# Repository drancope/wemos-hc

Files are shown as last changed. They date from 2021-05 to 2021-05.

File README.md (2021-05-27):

# This is first basic info for a Wemos Home Control project.
The first atempt was built in summer 2020, controls two ceiling lamps, and uses a wemos wired to the main door switches and to a kicad home made PCB with a pair of opto-couplers (moc3121) and triacs (bt136). It's been working for a year with only two reset problemas, before I engage in this description of the project and a propper redesign.
Two more wemos are also used to emit wifi orders (post http method). These ones are placed in the bed sides for convenience.
The main server creates its own local wifi lan, and mobile phones can get an ip and access the wemos web server, displaying a page where the user can turn on/off the lights.
Code is based on ESP8266 examples

# Goals:
- learning and experimenting with mc and electronics
 -- programming servers, use of wifi libraries
 -- making PCBs with power devices

- use of wemos minicontrollers to switch lights at home,
  -- server to accept mobile orders
  -- reliable if home router fails
  -- initially, does not depend on iot standards, but considering learning about that.
  
- Expandable
 -- accepting internet orders
   --- a second wemos wired to main wemos, to provide connection to local network.
   --- future use of cloud computing, or aws iot messages.

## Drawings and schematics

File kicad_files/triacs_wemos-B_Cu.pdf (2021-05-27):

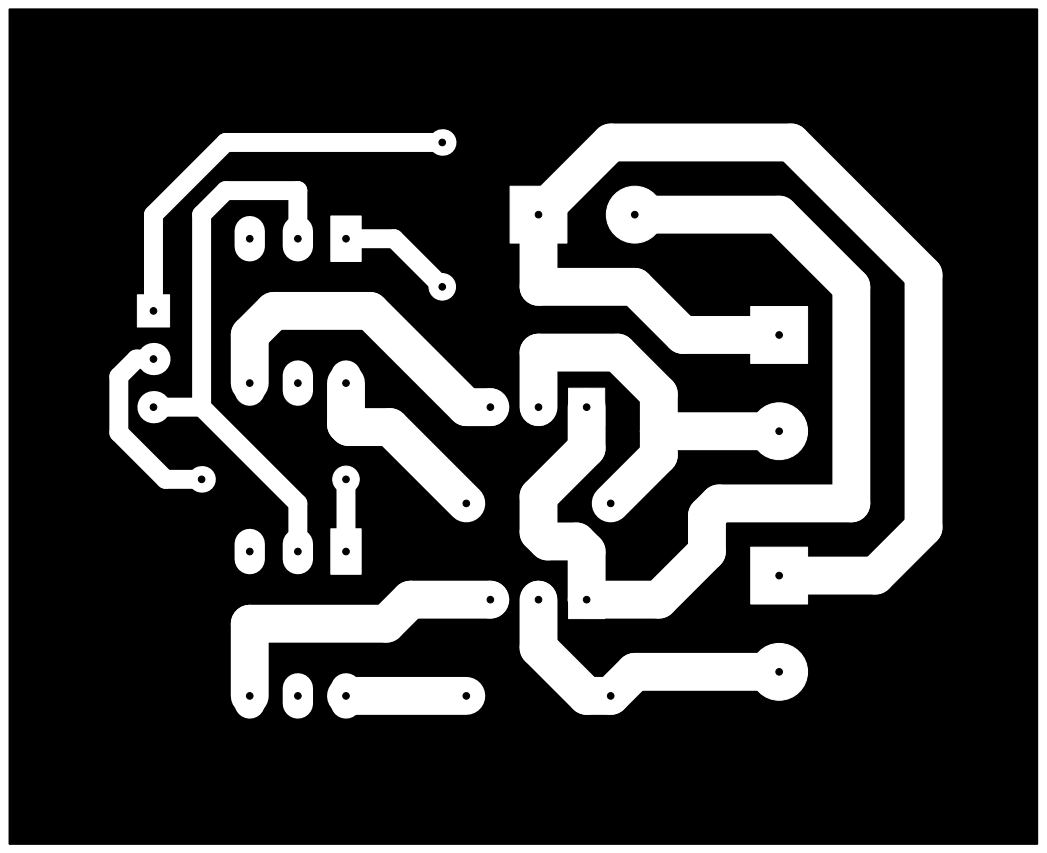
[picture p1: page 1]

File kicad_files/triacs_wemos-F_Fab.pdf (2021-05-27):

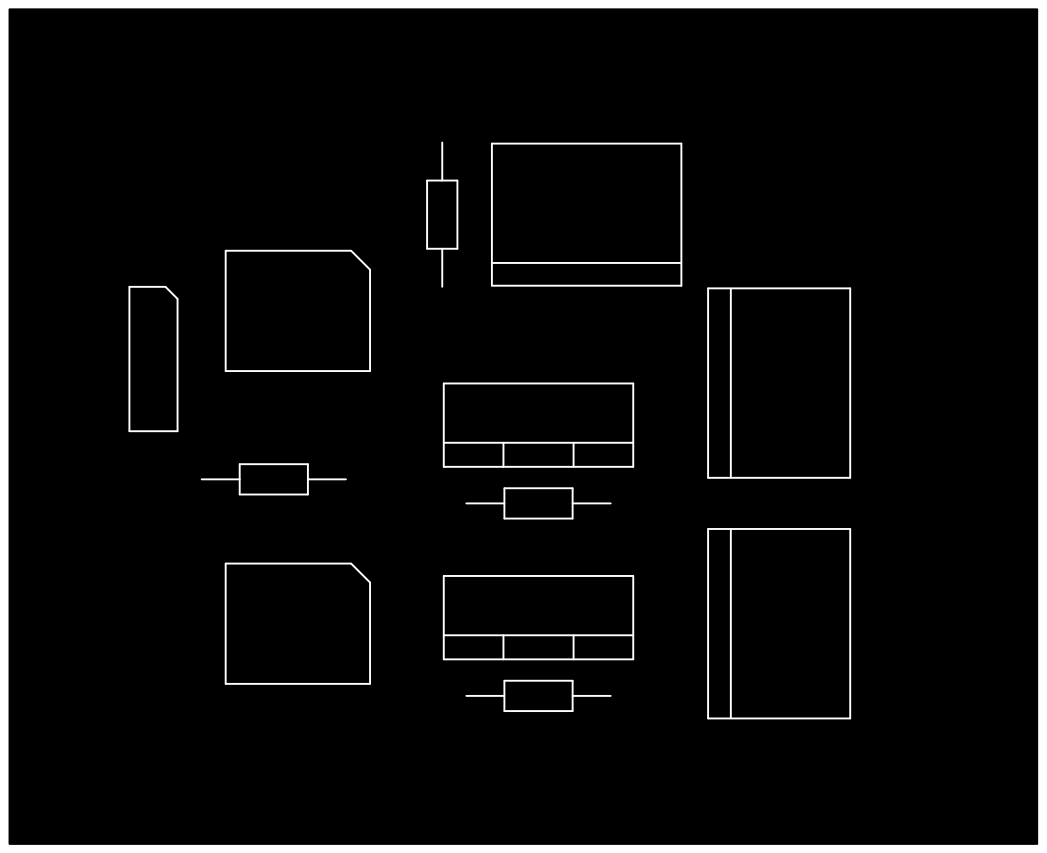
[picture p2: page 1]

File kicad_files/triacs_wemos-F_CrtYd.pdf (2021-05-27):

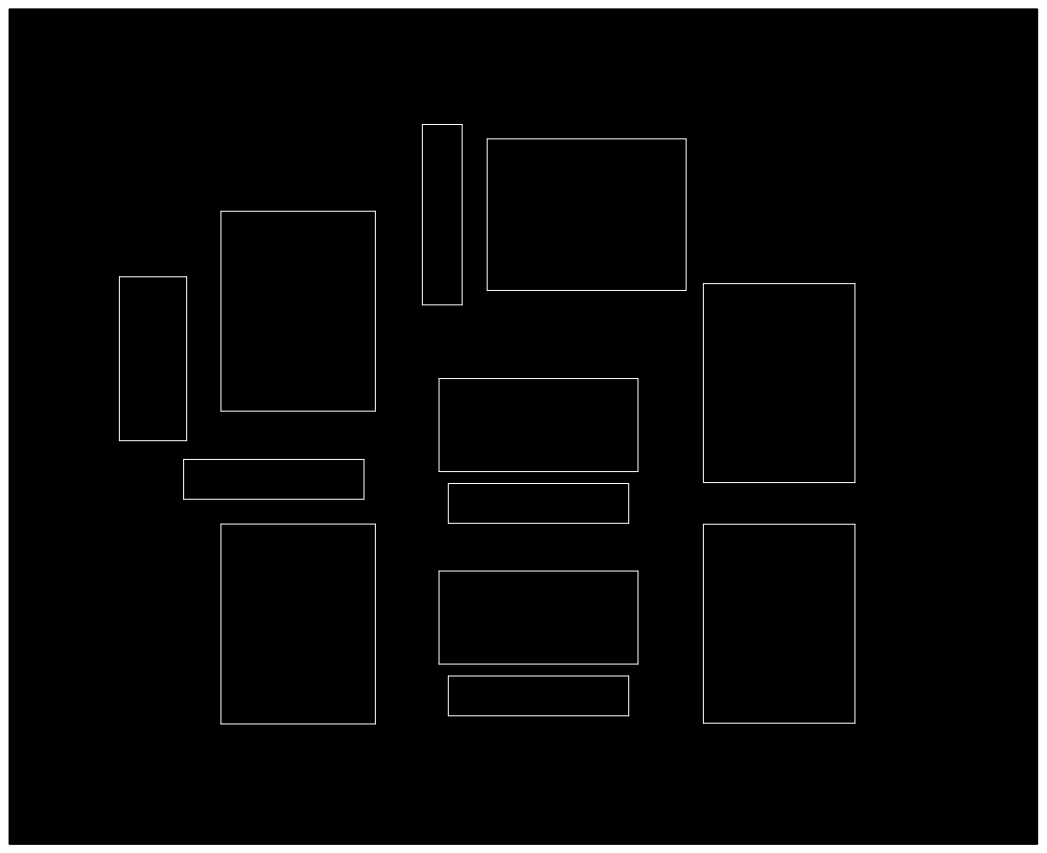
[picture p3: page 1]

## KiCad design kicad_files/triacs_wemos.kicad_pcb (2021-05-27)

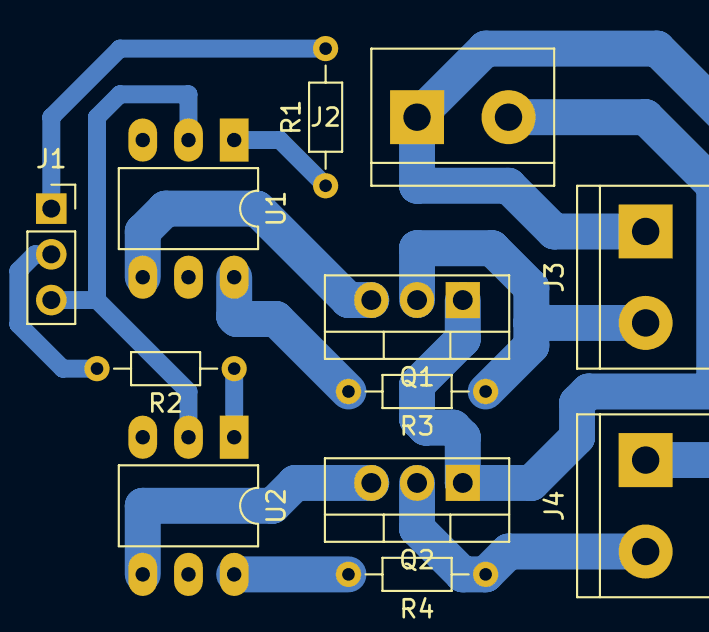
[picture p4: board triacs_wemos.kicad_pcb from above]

Board: 2 copper layers, 12 parts (0 on the bottom side), 13 nets.

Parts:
J1: Wemos; PinSocket_1x03_P2.54mm_Vertical
J2: Alim-altern; TerminalBlock_bornier-2_P5.08mm
J3: Luz 1; TerminalBlock_bornier-2_P5.08mm
J4: Luz 2; TerminalBlock_bornier-2_P5.08mm
Q1, Q2: BT136-600; TO-220-3_Vertical
R1, R2, R3, R4: R; R_Axial_DIN0204_L3.6mm_D1.6mm_P7.62mm_Horizontal
U1, U2: MOC3021M; DIP-6_W7.62mm_LongPads

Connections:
GND: J1.3, U1.2, U2.2
unnamed: J1.1, R1.2
unnamed: J1.2, R2.2
unnamed: J2.1, J3.1, J4.1
unnamed: J2.2, Q1.1, Q2.1
unnamed: J3.2, Q1.2, R3.1
unnamed: J4.2, Q2.2, R4.1
unnamed: Q1.3, U1.4
unnamed: Q2.3, U2.4
unnamed: R1.1, U1.1
unnamed: R2.1, U2.1
unnamed: R3.2, U1.6
unnamed: R4.2, U2.6

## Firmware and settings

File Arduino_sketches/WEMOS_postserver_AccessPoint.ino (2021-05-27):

#include <ESP8266WiFi.h>
#include <WiFiClient.h>
#include <ESP8266WebServer.h>
#include <ESP8266mDNS.h>
#include <string.h>

#ifndef STASSID
#define STASSID "your_wifi"
#define STAPSK  "your_wifi_passwd"
#endif
#ifndef APSSID
#define APSSID "this_wemos_wifi_access_point_name"
#define APPSK  "access_point_passwd"
#endif

#define SAL1 D3
#define SAL2 D2
#define ENT1 D5
#define ENT2 D6

const char *ssid     = APSSID;
const char *password = APPSK;
boolean estado1=0;
boolean estado2=0;

ESP8266WebServer server(80);

const int led = LED_BUILTIN;

const String postForms = "<html>\
  <head>\
    <title>ESP8266 Web Server POST handling</title>\
    <style>\
      body { background-color: #cccccc; font-size: xx-large; font-family: Arial, Helvetica, Sans-Serif; Color: #000088; }\
    </style>\
  </head>\
  <body>\
    <h1>POST plain text to /postplain/</h1><br>\
    <form method=\"post\" enctype=\"text/plain\" action=\"/postplain/\">\
      <div style=\"margin:10 80 40\">\
      <input type=\"submit\" style=\"font-size: 120px\" name=\"bot1\" value=\"1\"><br>\<br>\
      <input type=\"submit\" style=\"font-size: 120px\" name=\"bot2\" value=\"2\"><br>\
    </div>\
    </form>\
  </body>\
</html>";

const String redirige = "<html>\
    <head>\
        <meta http-equiv=\"refresh\" content=\"0; url=http://192.168.4.1/?\">\
<script type=\"text/javascript\">\
window.location.href = \"http://192.168.4.1\"\
</script>\
</head>\
</html>";


void handleRoot() {
  server.send(200, "text/html", postForms);
}

void handlePlain() {
  Serial.print(server.arg("plain"));
  
  if (server.method() != HTTP_POST) {
  //  server.send(405, "text/plain", "Method Not Allowed");
  } else {
   char dato = server.arg("plain")[5];
    if (dato=='1'){
      estado1 = !estado1;
      digitalWrite(SAL1, estado1);
    }
    else if (dato=='2') {
      estado2 = !estado2;
      digitalWrite(SAL2, estado2);
    }
   Serial.println(" recibido");
   Serial.print("Luz ");
   Serial.print(dato);
   switch(dato) {
    case '1':
     if (estado1==1) {Serial.println(" encendida");} else {Serial.println(" apagada");}
     break;
    case '2':
     if (estado2==1) {Serial.println(" encendida");} else {Serial.println(" apagada");}
     break;
    }
   }

    server.send(201, "text/html", redirige);
}
/*
void handleForm() {
  if (server.method() != HTTP_POST) {
  //  server.send(405, "text/plain", "Method Not Allowed");
  } else {
   char dato = server.arg("plain")[5];
   Serial.print(server.arg("plain"));
   Serial.println(" recibido");
    if (dato=='1'){
      estado1 = !estado1;
      digitalWrite(led, estado1);
    }
    else if (dato=='2') {
      estado2 = !estado2;
      digitalWrite(D3, estado2);
    }
    server.send(201, "text/html", redirige);
  }
}
*/
void handleNotFound() {
//  digitalWrite(led, 1);
  String message = "File Not Found\n\n";
  message += "URI: ";
  message += server.uri();
  message += "\nMethod: ";
  message += (server.method() == HTTP_GET) ? "GET" : "POST";
  message += "\nArguments: ";
  message += server.args();
  message += "\n";
  for (uint8_t i = 0; i < server.args(); i++) {
    message += " " + server.argName(i) + ": " + server.arg(i) + "\n";
  }
  server.send(404, "text/plain", message);
  Serial.println(message);
//  digitalWrite(led, 0);
}

void setup(void) {
  pinMode(SAL1, OUTPUT);
  pinMode(SAL2, OUTPUT);
  digitalWrite(SAL1, 0);
  digitalWrite(SAL2, 0);
  delay(400);
  Serial.begin(115200);
  Serial.println("");
  Serial.print("Configuring access point...");
  WiFi.softAP(ssid, password);
  IPAddress myIP = WiFi.softAPIP();
  Serial.print("AP IP address: ");
  Serial.println(myIP);
  server.on("/", handleRoot);
  server.on("/postplain/", handlePlain);
  server.onNotFound(handleNotFound);
  server.begin();
  Serial.println("HTTP server started");
  delay(1000);
  pinMode(SAL1, OUTPUT);
  pinMode(SAL2, OUTPUT);
  pinMode(ENT1, INPUT_PULLUP);
  pinMode(ENT2, INPUT_PULLUP);
  digitalWrite(SAL1, estado1);
  digitalWrite(SAL2, estado2);
}

void loop() {
  if (!digitalRead(ENT1)) {
    estado1 = !estado1;
    digitalWrite(SAL1, estado1);
    while(!digitalRead(ENT1)) {delay(20);}
  }
  if (!digitalRead(ENT2)) {
    estado2 = !estado2;
    digitalWrite(SAL2, estado2);
    while(!digitalRead(ENT2)) {delay(20);}
  }
  server.handleClient();
}

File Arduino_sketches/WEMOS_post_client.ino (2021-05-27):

/**
   PostHTTPClient.ino

    Created on: 21.11.2016

*/

#include <ESP8266WiFi.h>
#include <ESP8266HTTPClient.h>
#include <PolledTimeout.h>
#define USE_SERIAL Serial

/* this can be run with an emulated server on host:
        cd esp8266-core-root-dir
        cd tests/host
        make ../../libraries/ESP8266WebServer/examples/PostServer/PostServer
        bin/PostServer/PostServer
   then put your PC's IP address in SERVER_IP below, port 9080 (instead of default 80):
*/
//#define SERVER_IP "10.0.1.7:9080" // PC address with emulation on host
#define SERVER_IP "192.168.4.1"

#ifndef STASSID
#define STASSID "Wemos_access_point_name"
#define STAPSK  "access_point_password"
#endif
IPAddress ip(192, 168, 4, 2);
IPAddress gateway(192, 168, 4, 1);
IPAddress subnet(255, 255, 255, 0);
IPAddress dns1(192, 168, 4, 1);
//esp8266::polledTimeout::periodicFastUs halfPeriod(100000);

void setup() {
  pinMode(D5, INPUT_PULLUP);
  pinMode(D1, INPUT_PULLUP);

  USE_SERIAL.begin(115200);
  USE_SERIAL.println();

  WiFi.mode(WIFI_STA);
//  WiFi.config(ip, gateway, subnet, dns1);
  WiFi.begin(STASSID, STAPSK);

  while (WiFi.status() != WL_CONNECTED) {
    delay(500);
    USE_SERIAL.print(".");
  }
  USE_SERIAL.println("");
  USE_SERIAL.print("Connected! IP address: ");
  USE_SERIAL.println(WiFi.localIP());
 
}

void loop() {
  // wait for WiFi connection
  while (digitalRead(D5)) {
    yield();
  }
    if ((WiFi.status() == WL_CONNECTED)) {

    WiFiClient client;
    HTTPClient http;

    USE_SERIAL.print("[HTTP] begin...\n");
    // configure traged server and url
    http.begin(client, "http://"SERVER_IP"/postplain/"); //HTTP
    http.addHeader("Content-Type", "application/json");

    USE_SERIAL.print("[HTTP] POST...\n");
    // start connection and send HTTP header and body
    int httpCode = http.POST("bot1=1");
    USE_SERIAL.printf("[HTTP] POST... code: %d\n", httpCode);
        
    // httpCode will be negative on error
    if (httpCode > 0) {
      // HTTP header has been send and Server response header has been handled

      // file found at server
      if (httpCode == HTTP_CODE_OK) {
        const String& payload = http.getString();
        USE_SERIAL.println("received payload:\n<<");
        USE_SERIAL.println(payload);
        USE_SERIAL.println(">>");
      }
      while (!digitalRead(D5)) {delay(20);}
    } else {
      USE_SERIAL.printf("[HTTP] POST... failed, error: %s\n", http.errorToString(httpCode).c_str());
    }

    http.end();
  }
  delay(300);
}
